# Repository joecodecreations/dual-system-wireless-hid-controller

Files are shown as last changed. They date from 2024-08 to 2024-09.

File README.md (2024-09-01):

# The "HID Attack" To Wirelessly Control 2 Computers using 1 Mouse & Keyboard 
Created by [Joey Sanchez](https://github.com/joecodecreations)

1. [Introduction](#hardware-hid-attack-to-control-2-computers)
2. [What You Can Do with This Project](#what-you-can-do-with-this-project)
3. [Use Cases](#use-cases)
4. [Wiring](#wiring)
5. [Installation](#installation)
6. [Setup](#setup)
6. [Running the Software](#running-the-software)
7. [Testing Wireless / Debug](#testing-wireless-independently)
8. [3D printed Container](#3d-printed-container)

# Introduction

A hardware based approach to microsoft's "mouse without borders" where you can control two computers using a single keyboard and mouse but...it doesn't have to be windows and you don't need to run software on one of the computers.

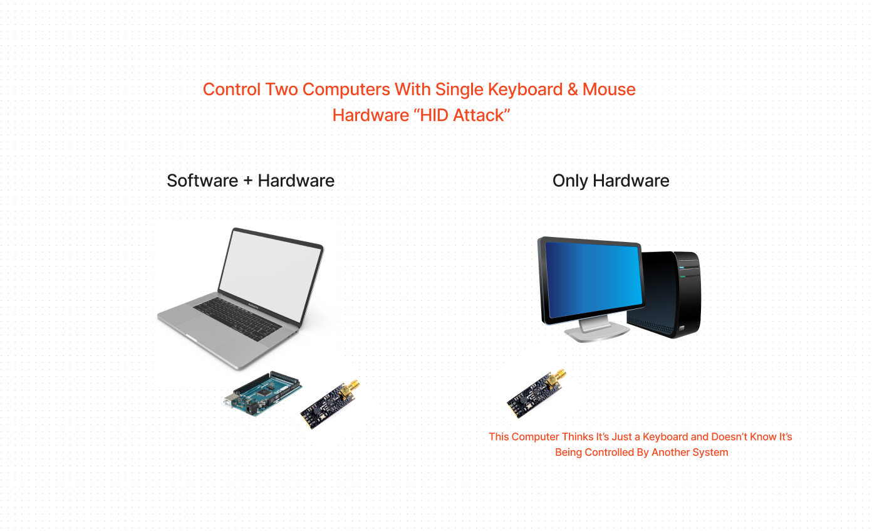
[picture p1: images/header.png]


## What you can do with this project

With this project, you can use software on a single system and then use two physical devices to control two computers. 

This leverages HID or human interface device attack vector to wirelessly transmit keystrokes and mouse movements to another computer. 

To accomplish this, we leverage two **ATMEGA32U4**s that can act as an HID, in combination with two **NRF24L01**s to provide wireless connectivity between the two devices. 

One ATMEGA32U4 can connect to your host machine via serial and get commands from a python script we have running which receives serial communication to the main ATMEGA32U4 which in turn, sends commands to the secondary ATMEGA32U4 via wireless over the **NRF24L01** and then allows keyboard and mouse control over a secondary system. 

The best part? The secondary computer doesn't know it's being controlled remotely since it "Trusts" the USB input as a keyboard device.

## Use Cases

1. While you can use [mouse without borders from miscrosoft](https://github.com/microsoft/PowerToys) between two windows machines, you cannot as easily control windows + linux or windows + mac combinations with that. *This* will work between *any* OS.

2. Due to security constraints, you may not be able to run software for sharing mice and keyboards on certain computers. Using this project, as long as you have a single computer you can control, this will allow you to control the ***other*** safely.

## Wiring 

First make sure you pick up 2 [NRF2401](https://www.amazon.com/dp/B08R9F11D1?ref=ppx_yo2ov_dt_b_fed_asin_title)s and two [ATmega32U4](https://www.amazon.com/dp/B08CC24JRS?ref=ppx_yo2ov_dt_b_fed_asin_title)s from your preferred electronics dealer.

You'll want to wire it up. I've color corrdinated for you to make it easier to seee my pictures. 

But basically the mapping is 

```
ATmega32U4 pins --- NRF2401 pins

pin 7   --- ce (green)
pin 8   --- csn (blue)
pin 15  --- sck (purple)
pin 16  --- mosi (white)
pin 14  --- Miso (grey)

```

I really appreciate the breakout board for the NRF2401. I also have some power supply regulators since I hear that the NRF2401 is really critical to use 3.5v with but requires higher amps than an arduino or ATmega32U4 could provide. 

**Here's the ATMEGA32U4 wired up:**

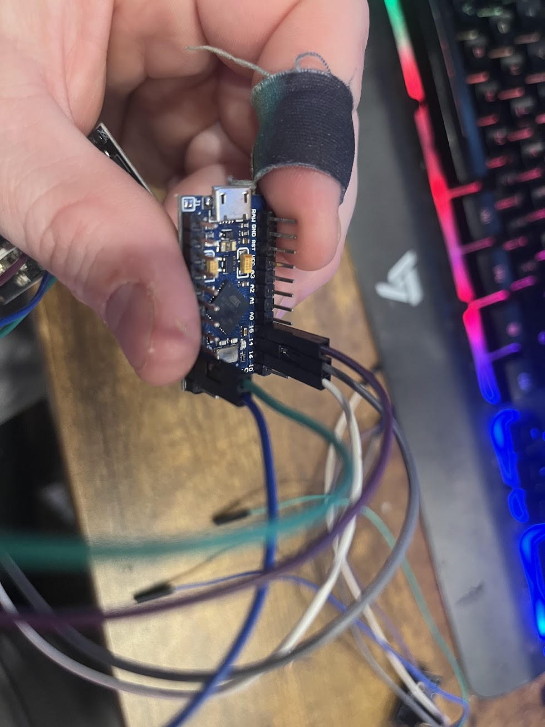
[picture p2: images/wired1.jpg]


**Make sure you share ground!**

Make sure you have the ATMEGA32U4 and the NRF2401 sharing grounds between the two units or else it may not know the correct baseline for the wireless signals coming in. 

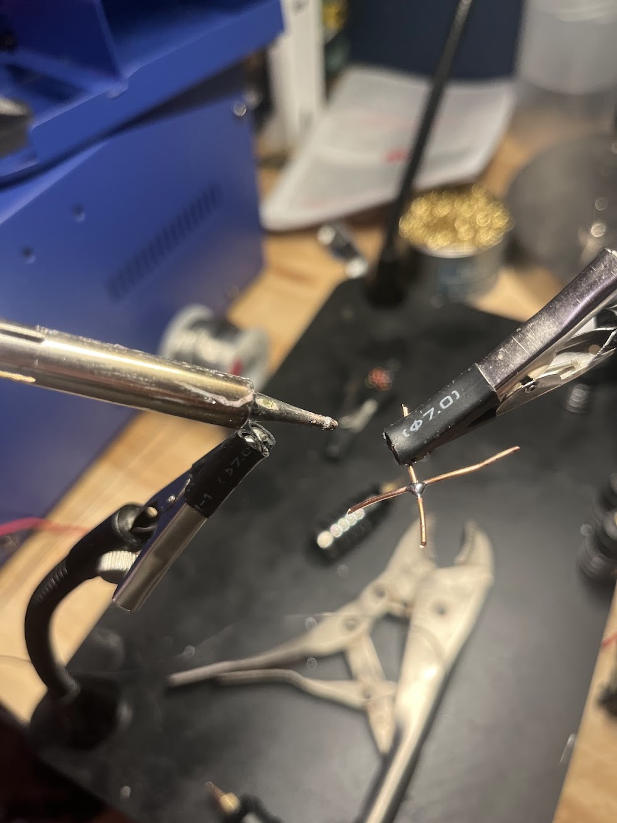
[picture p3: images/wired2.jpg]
Soldering For Common Grounds


**NRF24L01 wiring**

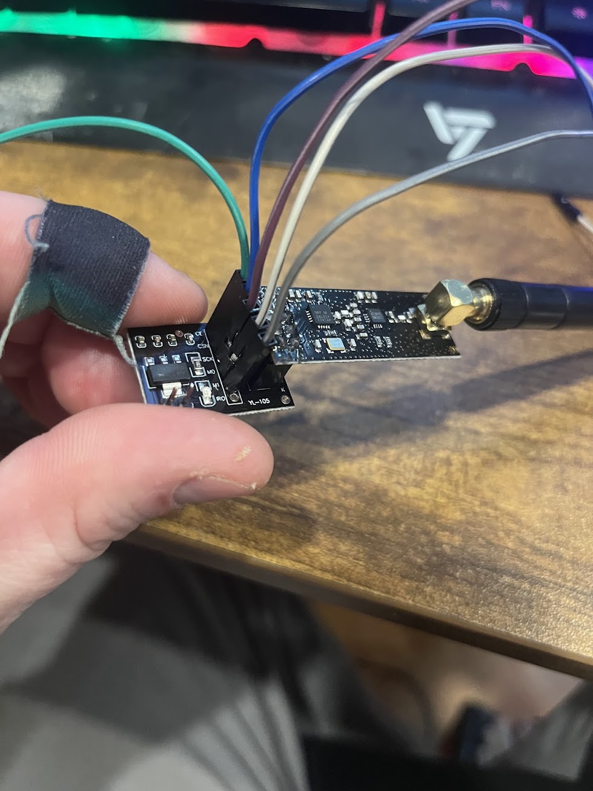
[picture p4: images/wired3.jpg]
NRF24L01 Wiring


# Installation

1. Run `pip install -r requirements.txt` to install the requirements

2. load `tx.ino` on one of the ATMEGA32U4s and `rx.ino` on the other. 

    You can use `Arduino` software to do this. 

# Setup

1. Open `app.py` and change your `target_system` to whatever you're going to control wirelessly (windows, mac, linux)

2. Update `host_system` to reflect whatever OS you'll be running this script on 

# Running the software 

run `python app.py` to kick things off. Then, you'll notice that when you take your cursor to the right side of the screen that it will start piping commands via serial to the tx.ino arduino.

When you come back the other direction, it will turn it off. 

## Running Indicator

Green Dot Indicator

You'll notice an indicator in the bottom right of your **host** system that indicates when the 
keyboard and mouse should be activated on your **target** system.

The dot is green but feel free to search `green` in the `app.py` and change it to `blue` or `red` or whatever.

## Operations
When you're controlling the other computer, you should be able to have full control of keyboard and mouse with all the mappings between systems working. 

For instance, if you've set your `target_system = "mac"` and your `host_system = "windows"`, when you hold `[left windows key]` + `[a]` it will `select all` on your target system.

# Testing Wireless Independently

To test the wireless is actually working correctly, you can install the alternative `.ino` files to test. RX on one mega and TX on the other (found in the comTests folder)

# 3D Printed Container

Okay, so now you have your hardware wired up, your software hopefully working and you'd like to put this in a container. I went ahead and included an STL file for the top and bottom of a container I created to house these. 
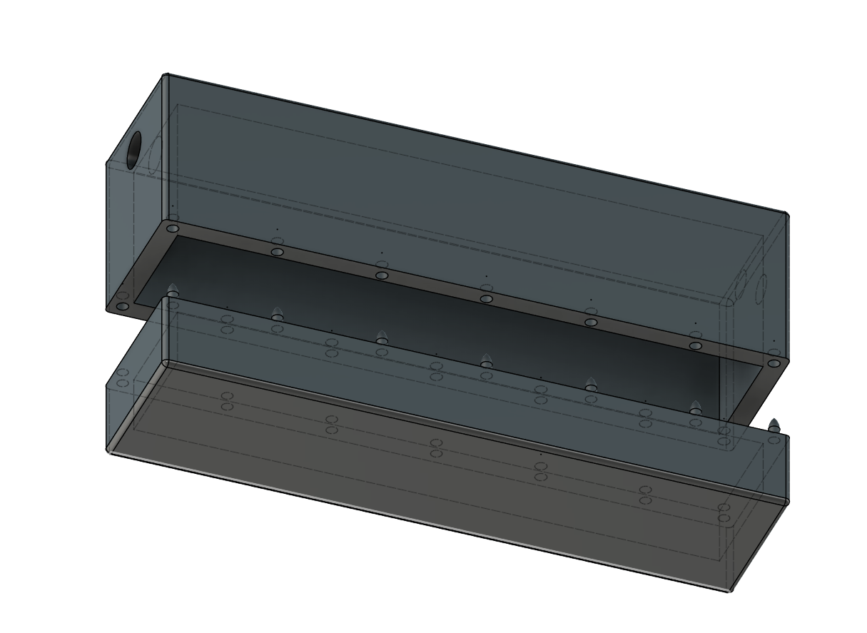
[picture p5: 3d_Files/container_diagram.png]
3D Diagram


The dimensions of this container is 

`40mm Height` X `22mm Width` X `112 Length` 

I has a 6mm hole for the cord and a 7mm hole for the antennea  

You can find these files in the `3d_files` folder

The sliced files are for a resin 3D printer but you can use the `.stl` files to import and slice with whatever software. 

There's also .obj files if you want to plop them somewhere to edit.

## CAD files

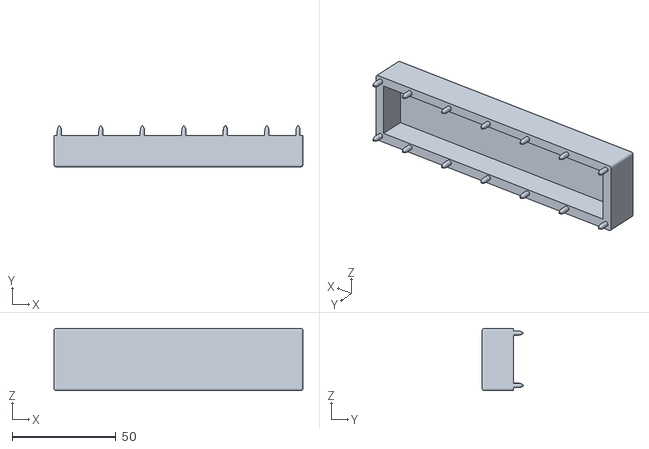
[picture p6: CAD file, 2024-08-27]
3d_Files/bottom.stl
120.0 x 20.0 x 30.0

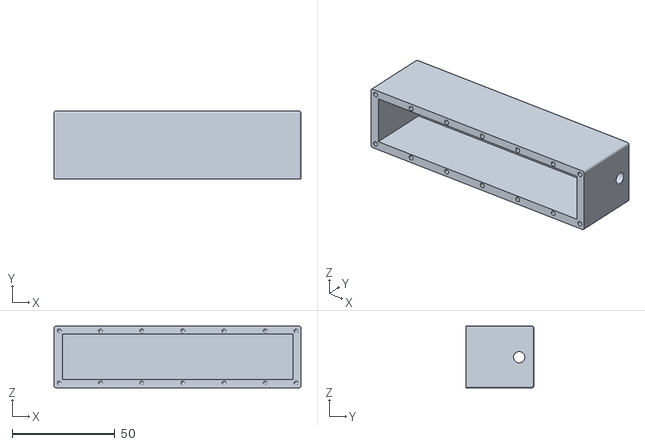
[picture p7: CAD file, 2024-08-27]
3d_Files/top.stl
120.0 x 33.0 x 30.0

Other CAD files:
3d_Files/bottom.obj
3d_Files/top.obj

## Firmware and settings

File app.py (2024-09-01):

import serial
import serial.tools.list_ports
import pyautogui
import mouse
import time
import keyboard
from screeninfo import get_monitors
import tkinter as tk

# set fail-safe to False
pyautogui.FAILSAFE = False

# Configuration
host_system = "windows"  # Options: "windows", "linux", "mac"
target_system = "mac"  # Options: "windows", "linux", "mac"


device_width= 2560
device_height= 1440

# Target computer's screen dimensions (e.g., MacBook Air M2 Retina)
target_width = 1728  # Width of the target computer's screen
target_height = 1117  # Height of the target computer's screen

# Global variables
mouse_left_click = False
mouse_right_click = False
mouse_left_released = False
mouse_right_released = False

log_microcontroller_messages = True
log_operational_messages = True
log_mouse_movement = False
log_key_presses = False


# Track sent mouse actions
mlc_sent = False  # Left click sent
mrc_sent = False  # Right click sent
mlcr_sent = False  # Left click released sent
mrcr_sent = False  # Right click released sent
special_keys_pressed = set()  # Initialize the set
isSpecialKeyPressed = False
keyboard_wait = False

off_system = False


# Define an array of keys that don't require the Shift key
keys_without_shift = [
    "a", "b", "c", "d", "e", "f", "g", "h", "i", "j", "k", "l", "m", "n", "o", "p",
    "q", "r", "s", "t", "u", "v", "w", "x", "y", "z", "1", "2", "3", "4", "5", "6",
    "7", "8", "9", "0", "`", "-", "=", "[", "]", ";", "'", ",", ".", "/", "\\",
    "A", "B", "C", "D", "E", "F", "G", "H", "I", "J", "K", "L", "M", "N", "O", "P",
    "Q", "R", "S", "T", "U", "V", "W", "X", "Y", "Z", "!", "@", "#", "$", "%", "^",
    "&", "*", "(", ")", "_", "+", "{", "}", "|", ":", '"', "<", ">", "?"

]
keys_with_shift = ["~", "!", "@", "#", "$", "%", "^", "&", "*", "(", ")", "_", "+", "{", "}", "|", ":", '"', "<", ">", "?"]
special_keys = [
    "shift",
    "ctrl",
    "alt",
    "space",
    "enter",
    "backspace",
    "tab",
    "esc",
    "up",
    "down",
    "left",
    "right",
    "capslock",
    "delete",
    "home",
    "end",
    "page up",
    "page down",
    "insert",
    "print screen",
    "pause",
    "cmd",
    "win",
    "super",
    "option",
    "right gui",
    "right shift",
    "right alt",
    "right control",
    "left gui",
    "left shift",
    "left alt",
    "left control",
    "left windows",
    "right windows",
]


def find_microprocessor_port():
    ports = list(serial.tools.list_ports.comports())
    for port in ports:
        # print(port.description)
        if (
            any(
                keyword in port.description
                for keyword in [
                    "Leonardo",
                    "Pro Micro",
                    "Uno",
                    "Mega",
                    "Arduino",
                    "USB Serial Device",  # Add comma here
                    "Microsoft Natural Ergonomic Keyboard 4000",
                ]
            )
            # or port.device == "COM24"
        ):
            print("Starting COMs with" + port.device)
            return port.device
    return None


def main():
    global tk, host_system, target_system, isSpecialKeyPressed, special_keys_pressed, special_keys, keyboard_wait, off_system, last_keys_pressed, log_mouse_movement, log_key_presses, log_operational_messages, log_microcontroller_messages
    global mlc_sent, mrc_sent, mlcr_sent, mrcr_sent  # Declare these as global to modify them inside the functions


    microprocessor_port = find_microprocessor_port()

    if microprocessor_port is None:
        print("Microcontroller not found. Please check the connection.")
        return

    try:
        ser = serial.Serial(microprocessor_port, 1000000, timeout=1, write_timeout=2)
        if log_microcontroller_messages:
            print(f"Connected to microcontroller on {microprocessor_port}")

        monitors = get_monitors()
        right_monitor = max(monitors, key=lambda m: m.x)

        # Host computer's screen dimensions
        host_width = right_monitor.width
        host_height = right_monitor.height



        edge_threshold = 40
        off_system = False
        last_keys_pressed = set()  # Initialize the set

        def scale_movement(value, host_max, target_max):
            """Scale movement from host screen size to target screen size."""
            return int((value / host_max) * target_max)

        def move_to_relative(x, y):
            absolute_x = right_monitor.x + x
            absolute_y = right_monitor.y + y
            mouse.move(absolute_x, absolute_y)

            if log_mouse_movement:
                print(f"Moved cursor to relative x={x}, y={y} on rightmost monitor")

        def on_left_click():
            global mlc_sent, mlcr_sent, mouse_left_click, mouse_left_released  # Global declaration

            mouse_left_click = True
            mlcr_sent = False
            mlc_sent = True
            mouse_left_released = False
            ser.write(f"C,1\n".encode())
            if log_key_presses:
                print("Left mouse button pressed")

        def on_right_click():
            global mrc_sent, mrcr_sent, mouse_right_click, mouse_right_released  # Global declaration
           
            mouse_right_click = True
            mrcr_sent = False
            mouse_right_released = False
            mrc_sent = True
            ser.write(f"C,3\n".encode())
            if log_key_presses:
                print("Right mouse button clicked")

        def on_left_release():
            global mlc_sent, mlcr_sent, mouse_left_click, mouse_left_released  # Global declaration
            # if not mlcr_sent:
            mouse_left_released = True
            mlc_sent = False
            mouse_left_click = False
            mlcr_sent = True
            ser.write(f"C,2\n".encode())
            if log_key_presses:
                print("Left mouse button released")

        def on_right_release():
            global mrc_sent, mrcr_sent, mouse_right_click, mouse_right_released  # Global declaration
            # if not mrcr_sent:
            mouse_right_released = True
            mrc_sent = False
            mouse_right_click = False
            mrcr_sent = True
            ser.write(f"C,4\n".encode())
            if log_key_presses:
                print("Right mouse button released")


        key_mapping = {
            "windows": {
                "ctrl": "ctrl",
                "alt": "alt",
                "win": "cmd",  # Treat Win on Windows as Cmd on Mac
                "shift": "shift",
                "delete": "delete",
                "backspace": "backspace",
                "enter": "enter",
                "home": "home",
                "end": "end",
                "pageup": "page up",
                "pagedown": "page down",
                "esc": "esc",
                "tab": "tab",
                "space": "space",
                "cmd": "win",  # Treat CMD on Mac as Win on Windows
                "left windows": "cmd",
            },
            "mac": {
                "ctrl": "ctrl",
                "option": "alt",  # Treat Option on Mac as Alt on Windows/Linux
                "cmd": "cmd",
                "shift": "shift",
                "delete": "backspace",  # Mac delete is equivalent to backspace
                "fn+delete": "delete",
                "return": "enter",
                "home": "home",
                "end": "end",
                "pageup": "page up",
                "pagedown": "page down",
                "esc": "esc",
                "tab": "tab",
                "space": "space",
                "super": "cmd",  # Treat Super on Linux as CMD on Mac
            },
            "linux": {
                "ctrl": "ctrl",
                "alt": "alt",
                "super": "super",
                "shift": "shift",
                "delete": "delete",
                "backspace": "backspace",
                "enter": "enter",
                "home": "home",
                "end": "end",
                "pageup": "page up",
                "pagedown": "page down",
                "esc": "esc",
                "tab": "tab",
                "space": "space",
                "cmd": "super"  # Treat CMD on Mac as Super on Linux
            }
        }

        special_key_map = {
            "shift": "KEY_LEFT_SHIFT",
            "ctrl": "KEY_LEFT_CTRL",
            "alt": "KEY_LEFT_ALT",
            "space": "KEY_SPACE",
            "enter": "KEY_RETURN",
            "backspace": "KEY_BACKSPACE",
            "tab": "KEY_TAB",
            "esc": "KEY_ESC",
            "up": "KEY_UP_ARROW",
            "down": "KEY_DOWN_ARROW",
            "left": "KEY_LEFT_ARROW",
            "right": "KEY_RIGHT_ARROW",
            "capslock": "KEY_CAPS_LOCK",
            "delete": "KEY_DELETE",
            "home": "KEY_HOME",
            "end": "KEY_END",
            "page up": "KEY_PAGE_UP",
            "page down": "KEY_PAGE_DOWN",
            "insert": "KEY_INSERT",
            "print screen": "KEY_PRINT_SCREEN",
            "pause": "KEY_PAUSE",
            "cmd": "KEY_LEFT_GUI",
            "win": "KEY_LEFT_GUI",
            "super": "KEY_LEFT_GUI",
            "option": "KEY_LEFT_ALT",
            "right gui": "KEY_RIGHT_GUI",
            "right shift": "KEY_RIGHT_SHIFT",
            "right alt": "KEY_RIGHT_ALT",
            "right control": "KEY_RIGHT_CTRL",
            "left gui": "KEY_LEFT_GUI",
        }

        # Arduino-specific mapping using Keyboard.h
        special_key_map = {
            "shift": "KEY_LEFT_SHIFT",
            "ctrl": "KEY_LEFT_CTRL",
            "alt": "KEY_LEFT_ALT",
            "space": "KEY_SPACE",
            "enter": "KEY_RETURN",
            "backspace": "KEY_BACKSPACE",
            "tab": "KEY_TAB",
            "esc": "KEY_ESC",
            "up": "KEY_UP_ARROW",
            "down": "KEY_DOWN_ARROW",
            "left": "KEY_LEFT_ARROW",
            "right": "KEY_RIGHT_ARROW",
            "capslock": "KEY_CAPS_LOCK",
            "delete": "KEY_DELETE",
            "home": "KEY_HOME",
            "end": "KEY_END",
            "page up": "KEY_PAGE_UP",
            "page down": "KEY_PAGE_DOWN",
            "insert": "KEY_INSERT",
            "print screen": "KEY_PRINT_SCREEN",
            "pause": "KEY_PAUSE",
            "cmd": "KEY_LEFT_GUI",
            "win": "KEY_LEFT_GUI",
            "super": "KEY_LEFT_GUI",
            "option": "KEY_LEFT_ALT",
            "right gui": "KEY_RIGHT_GUI",
            "right shift": "KEY_RIGHT_SHIFT",
            "right alt": "KEY_RIGHT_ALT",
            "right control": "KEY_RIGHT_CTRL",
            "left gui": "KEY_LEFT_GUI",
        }
        def connect_keyboard_listeners(prevent_system_output=False):
            global off_system
            if off_system:
                prevent_system_output = True
            keyboard.unhook(keyboard.on_press(handleKeys))
            keyboard.on_press(handleKeys, suppress=prevent_system_output)

        def map_key_to_arduino(input_os, target_os, key_pressed):
            # Normalize the key name to lowercase
            key_pressed_lowered = key_pressed.lower()

            # Step 1: Convert the key from the input OS to a general target key
            if input_os not in key_mapping:
                return key_pressed  # Unsupported OS

            target_key_intermediate = key_mapping[input_os].get(key_pressed_lowered, key_pressed_lowered)

            # Step 2: Convert the intermediate key to the target OS key
            if target_os not in key_mapping:
                return key_pressed  # Unsupported OS

            target_key_final = key_mapping[target_os].get(target_key_intermediate, target_key_intermediate)

            # Step 3: Map the final target key to an Arduino key code
            arduino_key_code = special_key_map.get(target_key_final.lower())

            if arduino_key_code:
                return arduino_key_code
            else:
                return target_key_final  # No mapping found, return the intermediate key as a fallback

                
        def send_Keys(handleSpecialKeys):
            global special_keys_pressed, isSpecialKeyPressed, target_system, keyboard_wait
            try:
                if not special_keys_pressed:
                    print("No key pressed")
                    return
                isSpecialKeyPressed = False
                keyboard_wait = False
                keys_to_send = set()

                # map special_key = special_key_map[key.name] for each key in special_keys_pressed or return character
                for key in special_keys_pressed:
                    if key in special_keys:
                        special_key_mapped = map_key_to_arduino(host_system, target_system, key)
                        if special_key_mapped is None:
                            special_key_mapped = key
                        keys_to_send.add(special_key_mapped)
                        break
                    else:
                        keys_to_send.add(key)


                # add back in any missing single characters to the list of keys to send
                for key in special_keys_pressed:
                    if key not in keys_to_send and len(key) == 1:
                        keys_to_send.add(key)
                # always make sure the keys to send are in the order of longest keys first
                keys_to_send = sorted(keys_to_send, key=len, reverse=True)

                if len(keys_to_send) == 1:
                    key = next(iter(special_keys_pressed))
                    if key in special_keys:
                        key = map_key_to_arduino(host_system, target_system, key)
                        ser.write(f"S,{key}\n".encode())
                    else:
                        ser.write(f"K,{key}\n".encode())
                    if log_key_presses:
                        print(f"Special Key pressed: {key}")
                else:
                    ser.write(f"X,{','.join(keys_to_send)}\n".encode())
                    if log_key_presses:
                        print(f"Multiple keys pressed: {','.join(keys_to_send)}")

                special_keys_pressed.clear()

            except Exception as e:
                print(f"Error while sending keys: {e}")
                

        def handleSpecialKeys(key):
            global keyboard_wait, special_keys, off_system, isSpecialKeyPressed, special_keys_pressed
            if off_system:
                if key.name in special_keys:
                        if key.event_type == keyboard.KEY_DOWN:
                            # if we didnt already press the special key
                            if key.name not in special_keys_pressed:
                                # add it to our array of key combinations
                                if log_key_presses:
                                    print(f"Special Key Added To Combo: {key.name}")
                                special_keys_pressed.add(key.name)
                                # track that we have pressed a special key so that all regular keys get added to combo
                                isSpecialKeyPressed = True
                                if log_key_presses:
                                    print(f"Special Key pressed DOWN: {key.name}")
                                keyboard.hook_key(key.name, handleSpecialKeys)
                        if key.event_type == keyboard.KEY_UP and key.name in special_keys_pressed:
                           if log_key_presses:
                               print(f"Special Key released: {key.name}")
                           send_Keys(handleSpecialKeys)
                           connect_keyboard_listeners(True)



        def handleKeys(key):
            global target_system, keyboard_wait, off_system, isSpecialKeyPressed, special_keys_pressed,keys_without_shift, keys_with_shift
            print('handle keys called')
            print(key)
            if key.name in special_keys:
                handleSpecialKeys(key)
            if off_system:
                character = key.name
                # handle key combinations
                if isSpecialKeyPressed:
                    print(f"Regular Key Added To Combo: {key.name}")
                    if key.event_type == keyboard.KEY_DOWN:
                        special_keys_pressed.add(key.name)
                        if log_operational_messages:
                            print(f"Key Combo gathering....adding: {key.name}")

                else:
                    # handle regular typing 
                    character = key.name
                    if character in keys_without_shift or character in keys_with_shift:
                        if not keyboard_wait:
                            keyboard_wait = True
                            if key.event_type == keyboard.KEY_DOWN:
                                ser.write(f"K,{key.name}\n".encode())
                                if log_key_presses:
                                    print(f"Key pressed DOWN: {key.name}")
                                keyboard_wait = False

        def handleMouseClick(event):
            global off_system

            # Ensure the event is a ButtonEvent (ignoring MoveEvent, WheelEvent, etc.)
            if off_system and isinstance(event, mouse.ButtonEvent):
                event_type = event.event_type
                button = event.button
                pressed = event_type == "down"

                if button == mouse.LEFT:
                    if pressed:
                        on_left_click()
                    else:
                        on_left_release()
                elif button == mouse.RIGHT:
                    if pressed:
                        on_right_click()
                    else:
                        on_right_release()
                # prevent the event from propagating further
            return False
        
        def remove_keyboard_listeners():
            if log_operational_messages:
                print("Removing keyboard listeners")
            keyboard.unhook_all()

        def hide_cursor():
            # Move the mouse cursor to the corner of the screen (or off-screen)
            pyautogui.moveTo(-4000, -4000)
        def show_cursor():
            # Move the mouse cursor to the corner of the screen (or off-screen)
            pyautogui.moveTo(4000, 4000)
        # Create a Tkinter root window
        root = tk.Tk()
        root.overrideredirect(True)  # Remove window decorations (title bar, etc.)
        root.attributes("-topmost", True)  # Keep the window on top
        root.geometry(f"10x10+{right_monitor.x + right_monitor.width - 20}+{right_monitor.y + right_monitor.height - 20}")  # Position the window

      
        # Create a label to display the icon (a simple colored square in this example)
        icon_label = tk.Label(root, bg="green")
        icon_label.pack(fill=tk.BOTH, expand=True)

        def show_icon():
            root.deiconify()  # Show the window

        def hide_icon():
            root.withdraw()  # Hide the window

        hide_icon()  # Start with the icon hidden

        
        mouse.hook(handleMouseClick)
        
        def check_position():
            global off_system, log_mouse_movement, log_operational_messages
            try:
                x, y = mouse.get_position()

                if log_mouse_movement:
                    print(f"Mouse position: x={x}, y={y} | Off-system: {off_system}")

                if right_monitor.y <= y <= right_monitor.y + right_monitor.height:
                    if (
                        x >= right_monitor.x + right_monitor.width - edge_threshold
                        and not off_system
                    ):
                        off_system = True
                        hide_cursor()
                        connect_keyboard_listeners(True)
                        show_icon()  # Show the icon when switching to the target system
                        if log_operational_messages:
                            print("Switching to target system...")

                        mouse.move(right_monitor.x - 10000, y)  # Move cursor off-screen
                        time.sleep(0.1)

                    elif x <= right_monitor.x + edge_threshold and off_system:
                        off_system = False
                        show_cursor()
                        remove_keyboard_listeners()
                        hide_icon()  # Hide the icon when switching back to the host system
                        if log_operational_messages:
                            print("Switching back to host system...")

                        move_to_relative(right_monitor.width - 2, y - right_monitor.y)
                        time.sleep(0.2)

                if off_system:
                    if log_mouse_movement:
                        print(f"Sending x={x}, y={y}")
                        # scale from device to target movements
                        scale_factor_width = target_width / device_width
                        scale_factor_height = target_height / device_height
                        x = scale_factor_width * x
                        y = scale_factor_height * y
                    ser.write(f"M{x},{y}\n".encode())

            except Exception as e:
                print(f"Error occurred in loop: {e}")
            
            root.after(20, check_position)  # Schedule this function to run again after 20 ms

        check_position()  # Start the loop
        root.mainloop()  # Start the Tkinter event loop

    except Exception as e:
        print(f"Error occurred during setup: {e}")


if __name__ == "__main__":

    main()

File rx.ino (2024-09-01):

#include <SPI.h>
#include <RF24.h>
#include <RF24Network.h>
#include <Mouse.h>
#include <Keyboard.h>

RF24 radio(7, 8);               // nRF24L01(+) radio attached using Getting Started board
RF24Network network(radio);     // Network uses that radio
const bool LogSerial = false; // turn on to log serial output for testing, open serial monitor in arduino for program to actually work if this gets turned on
const uint16_t this_node = 00;  // Address of our node in Octal format
const uint16_t other_node = 01; // Address of the other node in Octal format

// Structure of our payload
struct payload_t {
  uint8_t type;  // 0 for mouse movement, 1 for mouse click, 2 for keyboard input
  int8_t x;      // For mouse: x movement; For keyboard: key code; For click: button (1=left, 2=right)
  int8_t y;      // For mouse: y movement; For keyboard and click: not used
  char message[128]; // larger payloads
  bool isPressed;
};

bool skipMove = false;
bool initialPayloadReceived = false;
int lastX = 0;
int lastY = 0;

struct KeyMap {
    const char* name;
    uint8_t keyCode;
};

KeyMap specialKeyMap[] = {
    {"KEY_LEFT_CTRL", KEY_LEFT_CTRL},
    {"KEY_LEFT_SHIFT", KEY_LEFT_SHIFT},
    {"KEY_LEFT_ALT", KEY_LEFT_ALT},
    {"KEY_LEFT_GUI", KEY_LEFT_GUI},  // Windows key on most keyboards
    {"KEY_RIGHT_CTRL", KEY_RIGHT_CTRL},
    {"KEY_RIGHT_SHIFT", KEY_RIGHT_SHIFT},
    {"KEY_RIGHT_ALT", KEY_RIGHT_ALT},
    {"KEY_RIGHT_GUI", KEY_RIGHT_GUI},  // Windows key on most keyboards
    
    {"KEY_UP_ARROW", KEY_UP_ARROW},
    {"KEY_DOWN_ARROW", KEY_DOWN_ARROW},
    {"KEY_LEFT_ARROW", KEY_LEFT_ARROW},
    {"KEY_RIGHT_ARROW", KEY_RIGHT_ARROW},
    
    {"KEY_BACKSPACE", KEY_BACKSPACE},
    {"KEY_TAB", KEY_TAB},
    {"KEY_RETURN", KEY_RETURN},      // Enter key
    {"KEY_ESC", KEY_ESC},
    {"KEY_INSERT", KEY_INSERT},
    {"KEY_DELETE", KEY_DELETE},
    {"KEY_PAGE_UP", KEY_PAGE_UP},
    {"KEY_PAGE_DOWN", KEY_PAGE_DOWN},
    {"KEY_HOME", KEY_HOME},
    {"KEY_END", KEY_END},
    
    {"KEY_CAPS_LOCK", KEY_CAPS_LOCK},
    {"KEY_F1", KEY_F1},
    {"KEY_F2", KEY_F2},
    {"KEY_F3", KEY_F3},
    {"KEY_F4", KEY_F4},
    {"KEY_F5", KEY_F5},
    {"KEY_F6", KEY_F6},
    {"KEY_F7", KEY_F7},
    {"KEY_F8", KEY_F8},
    {"KEY_F9", KEY_F9},
    {"KEY_F10", KEY_F10},
    {"KEY_F11", KEY_F11},
    {"KEY_F12", KEY_F12},

    {"KEY_PRINT_SCREEN", KEY_PRINT_SCREEN},
    {"KEY_SCROLL_LOCK", KEY_SCROLL_LOCK},
    {"KEY_PAUSE", KEY_PAUSE},

    {"KEY_NUM_LOCK", KEY_NUM_LOCK},

    {"KEYPAD_0", KEY_KP_0},   // Keypad 0
    {"KEYPAD_1", KEY_KP_1},   // Keypad 1
    {"KEYPAD_2", KEY_KP_2},   // Keypad 2
    {"KEYPAD_3", KEY_KP_3},   // Keypad 3
    {"KEYPAD_4", KEY_KP_4},   // Keypad 4
    {"KEYPAD_5", KEY_KP_5},   // Keypad 5
    {"KEYPAD_6", KEY_KP_6},   // Keypad 6
    {"KEYPAD_7", KEY_KP_7},   // Keypad 7
    {"KEYPAD_8", KEY_KP_8},   // Keypad 8
    {"KEYPAD_9", KEY_KP_9},   // Keypad 9

    {"KEYPAD_DIVIDE", KEY_KP_SLASH},      // Keypad /
    {"KEYPAD_MULTIPLY", KEY_KP_ASTERISK}, // Keypad *
    {"KEYPAD_SUBTRACT", KEY_KP_MINUS},    // Keypad -
    {"KEYPAD_ADD", KEY_KP_PLUS},          // Keypad +
    {"KEYPAD_ENTER", KEY_KP_ENTER},       // Keypad Enter
    {"KEYPAD_DOT", KEY_KP_DOT},           // Keypad .

    {"KEY_SPACE", ' '},  // Space can be represented by the space character


};

uint8_t findKeyCode(const char* keyName) {
    for (const auto& key : specialKeyMap) {
        if (strcmp(key.name, keyName) == 0) {
            return key.keyCode;
        }
    }
    return 0;  // Return 0 if not found, 0 usually means "no key"
}

void handleSpecialKey(const char* message, bool isPressed) {
    uint8_t keyCode = findKeyCode(message);
    if (keyCode != 0) {
        if (isPressed) {
            Keyboard.press(keyCode);
            Keyboard.release(keyCode);
        } else {
            Keyboard.release(keyCode);
        }
    }
}

void setup(void) {
  if (LogSerial) {
    Serial.begin(1000000);
    while (!Serial) {
        // some boards need this because of native USB capability
    }

    Serial.println(F("Serial Started..."));
  }


  if (!radio.begin()) {
    if (LogSerial) {
        Serial.println(F("Radio hardware not responding!"));
    }

    while (1) {
      // hold in infinite loop
    }
  }
  radio.setPALevel(RF24_PA_MAX);  // Set power to maximum
  radio.setDataRate(RF24_2MBPS);  // Set data rate to 2Mbps
  radio.setChannel(90);
  network.begin(this_node);

  Mouse.begin();    // Initialize mouse control
  Keyboard.begin(); // Initialize keyboard control
}

void loop(void) {
  network.update();  // Check the network regularly

  while (network.available()) {  // Is there anything ready for us?
    RF24NetworkHeader header;    // If so, grab it
    payload_t payload;
    network.read(header, &payload, sizeof(payload));

    if (!initialPayloadReceived) {
      // Store the first received payload as the initial reference point
      lastX = payload.x;
      lastY = payload.y;
      initialPayloadReceived = true;

      if(LogSerial){
        Serial.println(F("Initial payload received. No mouse movement yet."));
      }
    } else {
      switch (payload.type) {
        case 0: {  // Mouse movement
          // Calculate the difference from the last payload
          int deltaX = payload.x - lastX;
          int deltaY = payload.y - lastY;

          // Move the mouse according to the difference
          Mouse.move(deltaX, deltaY);

          // Store the current payload as the last one for the next iteration
          lastX = payload.x;
          lastY = payload.y;
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

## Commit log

2024-08-26 adding better search for device finding, muting serial output for rx.ino
2024-08-26 remove duplicate keys being sent in error
    [app.py]
2024-08-26 mouse clicks and releases handled independently so we can highlight text, increased baud rate for serial, moved mouse clicks to global mouse listener, not handling key press and key release yet so wh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
    [app.py, rx.ino, tx.ino]
2024-08-27 adding 3D files
    [bottom.obj, bottom.stl, top.obj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]
2024-08-28 - adding dot indicator on screen when controlling target computer
    - cleaning up logs
    - flipping serial log default for rx.ino back to off
    [app.py, rx.ino]
2024-08-28 working typing through endpoint, allowing remote turn off of mouse and keyboard switching to target
